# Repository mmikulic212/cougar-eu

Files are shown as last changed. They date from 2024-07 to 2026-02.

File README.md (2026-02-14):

# Throttle Cougar Extended Upgrade

Hardware upgrade for ThrustMaster Cougar TQS throttle quadrant.

## Goal

Enable ThrustMaster Cougar throttle to work independently from Cougar stick, with additional switches and encoders. Uses native USB HID - no additional drivers required.

## MMJoy Firmware

This project uses [MMJoy](https://github.com/MMJoy/mmjoy_en) - open-source USB HID joystick firmware for Arduino.

- **Download**: https://github.com/MMJoy/mmjoy_en/releases
- **Wiki**: https://github.com/MMjoy/mmjoy_en/wiki

## MMJoy Configuration Files

Two pre-configured MMJoy settings are included in `mmjoy_setup/`:

### tm_cougar_mlu_32b+hat.mmjoy
- **32 buttons** + hat switch
- 6 axes (throttle, X, Y, rX, rY, Slider)
- CRS (course) controls mapped as **axes**

### tm_cougar_mlu_36b+hat_crs_asbut.mmjoy
- **36 buttons** + hat switch (32 + **4 additional** buttons)
- 6 axes (throttle, X, Y, rX, rY, Slider)
- CRS (course) controls mapped as **buttons** (for target cursor control in simulators)

Both configurations work identically. Choose 36-button version if you want to control target cursor with buttons instead of axes.

## Hardware

### Required Components

| Component | Description | Example |
|---|---|---|
| ThrustMaster Cougar TQS | Original throttle quadrant | N/A |
| Custom PCB | Interface board | Order package in `order/` |
| Arduino Pro Micro | USB HID controller (ATmega 32u4) | Generic clone, 5V/16MHz, USB-C version is recommended |
| 1x 2x8-pin connector | For throttle button matrix | 2x8-pin connector |

### Optional Components

| Component | Description | Example |
|---|---|---|
| 3x 74HC165 | 8-bit shift register | SN74HC165N DIP-16 |
| 9x Toggle Switch | (ON)-OFF-(ON) DPDT | RS PRO 206-6978 |
| 2x Rotary Encoder | KY-040 with push button | KY-040 module |
| 1x 24-pin DIP socket | For Arduino Pro Micro | |
| 3x 16-pin DIP socket | For 74HC165 | 16-pin DIP socket |
| 3x 10-pin connector | For additional buttons (2x5 IDC header) | 10-pin connector |
| Ribbon cable | 10-pin flat cable | or other cables |

### Recomendation

Orignal throttle and other axis potenciometers can stay and work very wel. But I strongly recommend upgrade to Hall sensors. Unfortunatelly this is still  WIP from my side.

## Wiring and Pinout

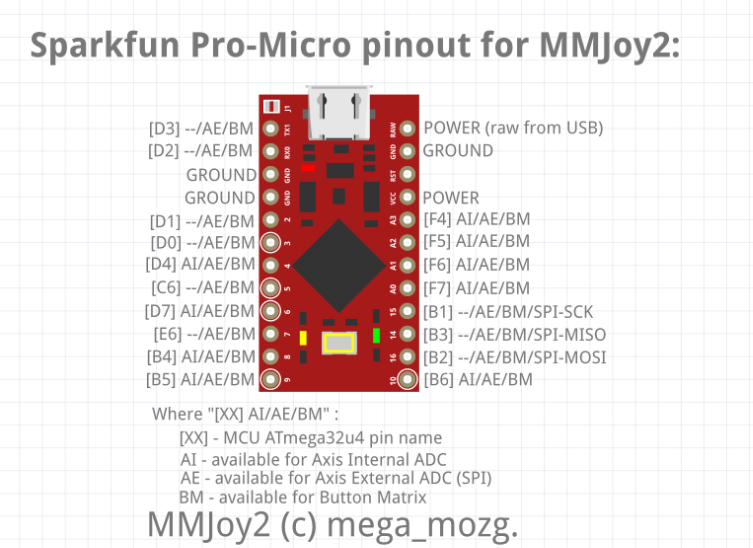
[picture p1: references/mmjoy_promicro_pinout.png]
Pro Micro Pinout


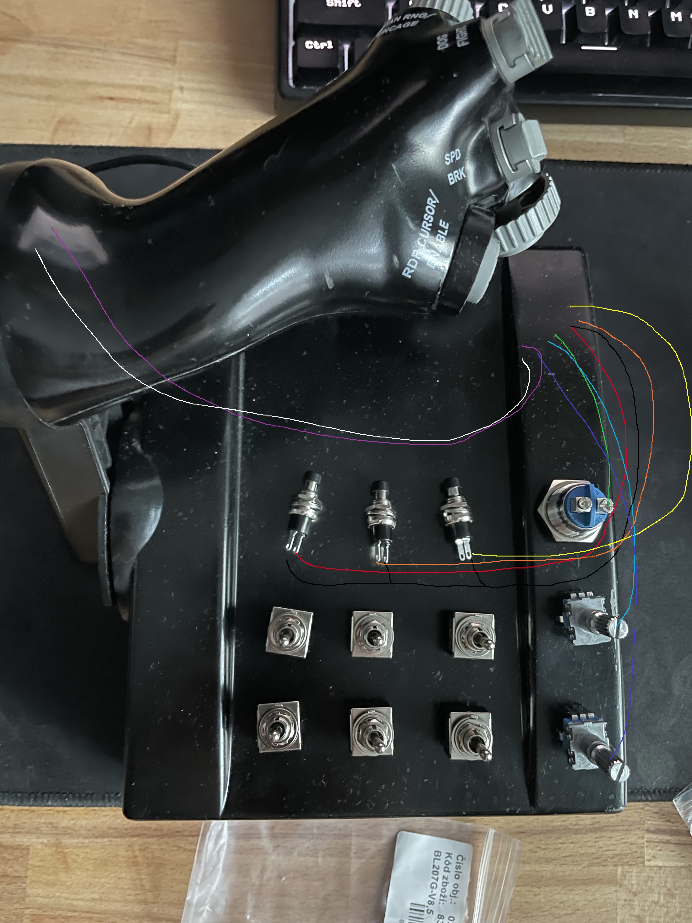
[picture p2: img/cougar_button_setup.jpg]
Button Setup


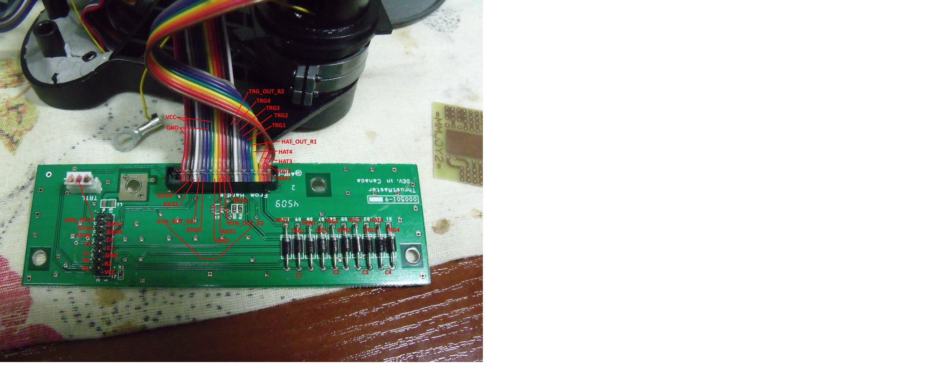
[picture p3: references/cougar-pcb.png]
Cougar PCB Description


### Assembly Images

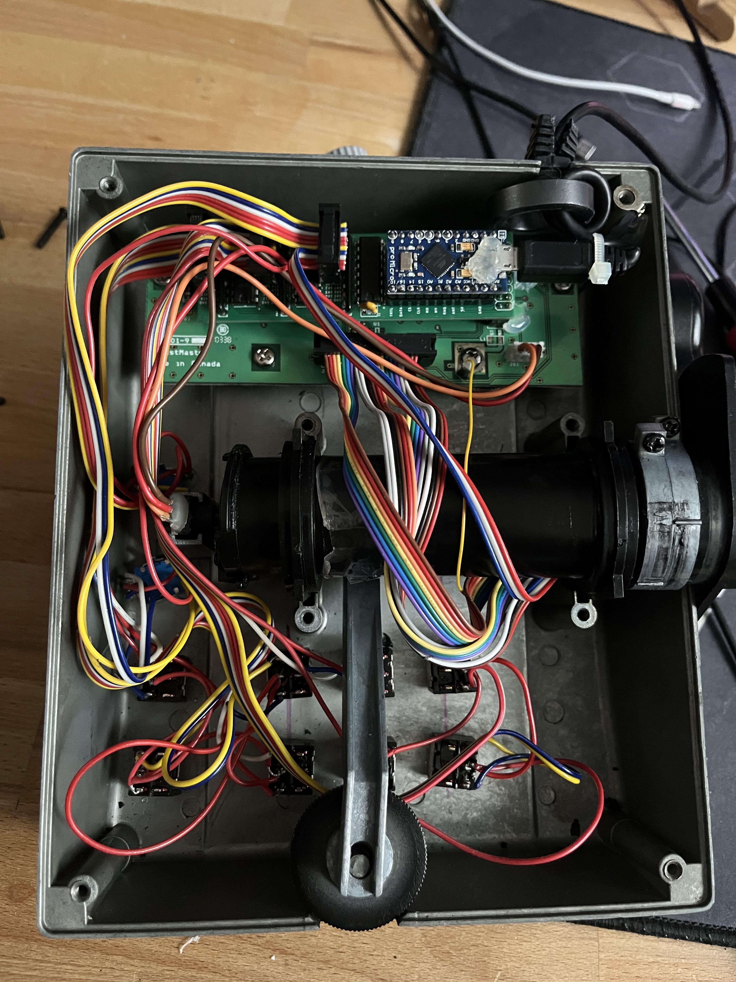
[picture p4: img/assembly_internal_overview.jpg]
Internal Overview

*Internal view showing PCB, Arduino Pro Micro, shift registers, and wiring*

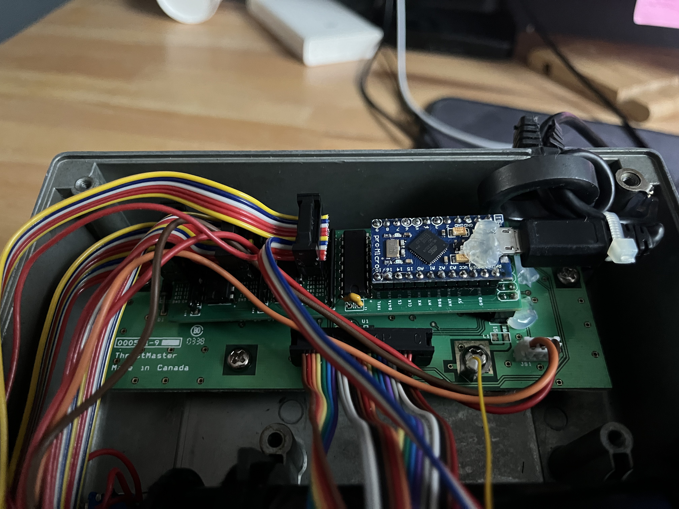
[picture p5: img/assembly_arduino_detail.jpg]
Arduino Detail

*Close-up of Arduino Pro Micro installed in socket with connected wires*

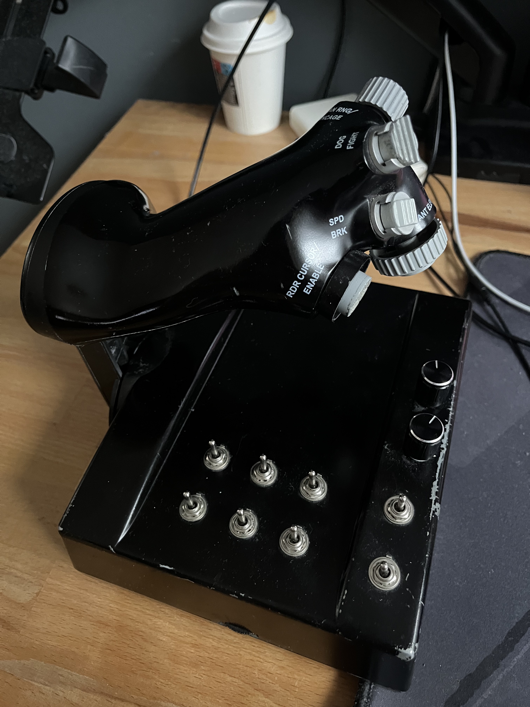
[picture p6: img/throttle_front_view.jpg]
Front View

*Front view of completed throttle with toggle switches*

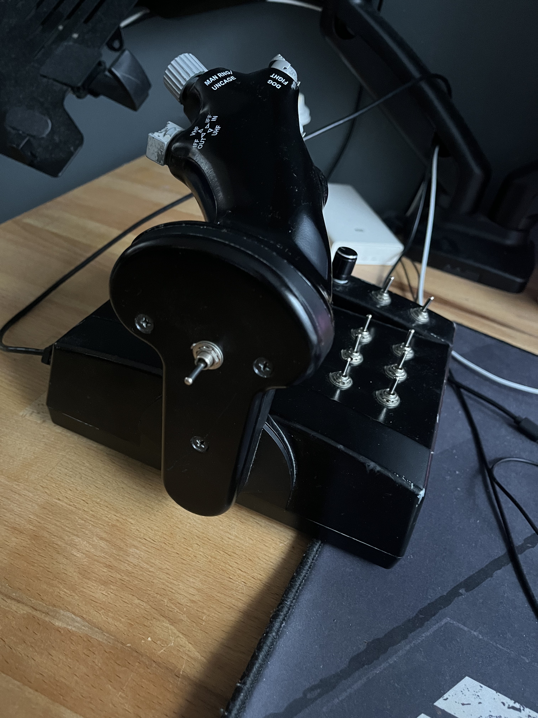
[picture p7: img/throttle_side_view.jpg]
Side View

*Side view showing throttle grip and switch placement*

The custom PCB can be ordered from any PCB manufacturer (JLCPCB, PCBWay, Seeed, etc.) using Gerber files in `order/` folder.

**No electrical modifications to Cougar throttle are required** - simply connect the custom PCB onto Cougar PCB 2x8 DIP connector and connect via USB.

## Getting Started

1. **Order PCB** - Download Gerber files from `order/` folder
2. **Assemble** - Solder components, install Arduino and shift registers in sockets, connect to throttle
3. **Flash firmware** - Upload MMJoy to Arduino Pro Micro ([see MMJoy Wiki](https://github.com/MMjoy/mmjoy_en/wiki/Firmware-upload))
4. **Configure** - Use MMJoy configurator to set up inputs/outputs. Load configuration from `mmjoy_setup/` and modify based on your wiring
5. **Test** - Verify all buttons, encoders, and axes work correctly

## Project Structure

| Folder | Description |
|---|---|
| `board/` | PCB design files (Eagle) |
| `mmjoy_setup/` | MMJoy configuration files |
| `order/` | Gerber files for PCB manufacturing |
| `references/` | Reference documentation |

## License

CC BY-NC-SA 4.0 - Non-commercial use only, share-alike

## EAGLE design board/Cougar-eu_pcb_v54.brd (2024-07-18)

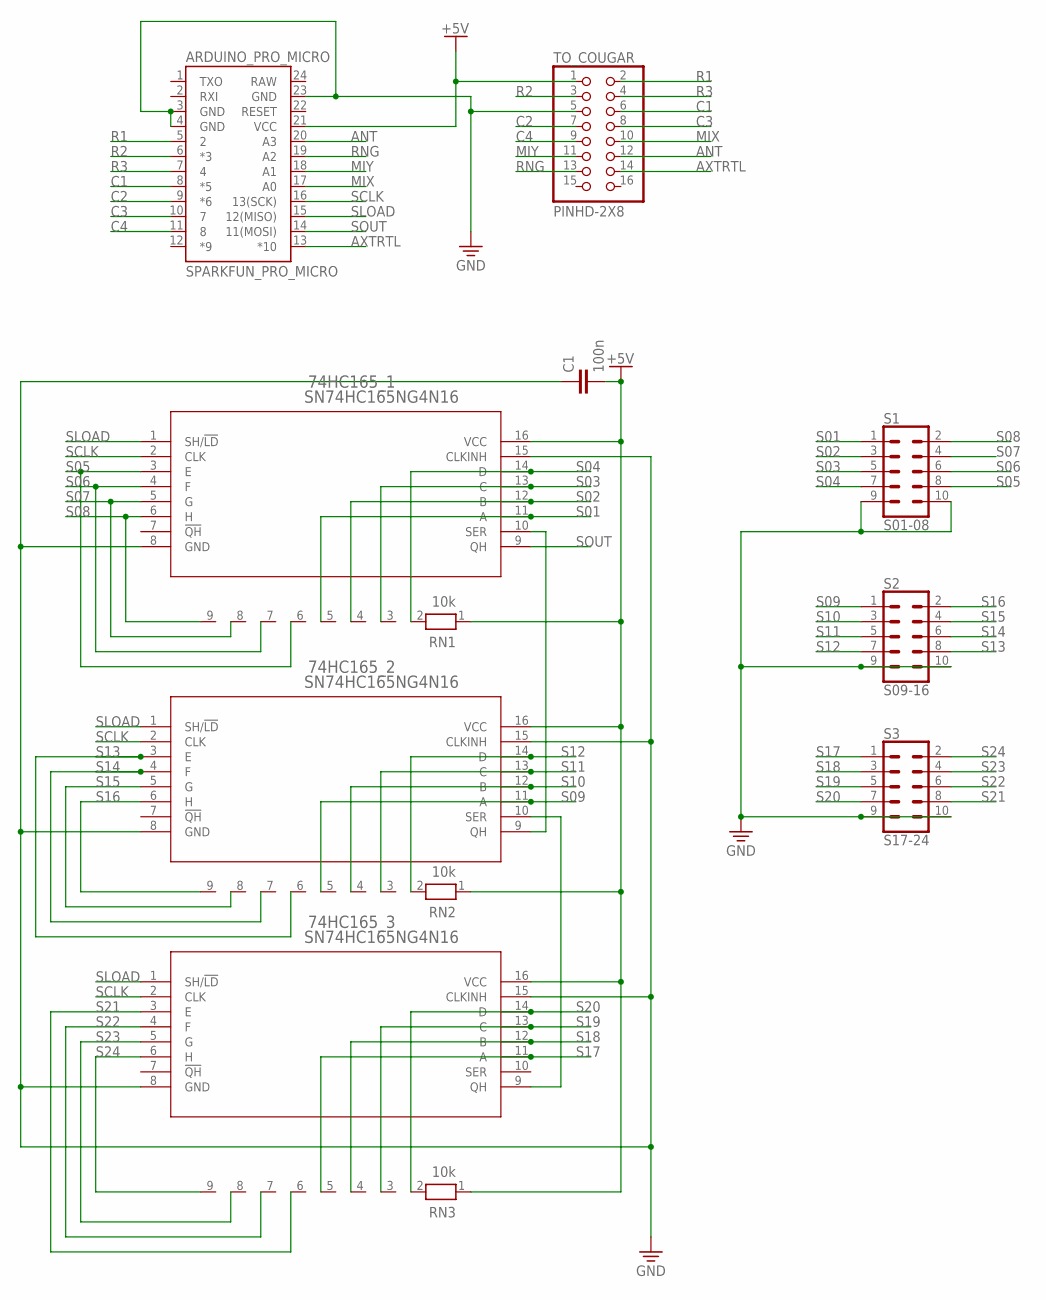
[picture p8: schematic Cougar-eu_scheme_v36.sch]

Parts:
74HC165_1, 74HC165_2, 74HC165_3: SN74HC165NG4N16; N16
ARDUINO_PRO_MICRO: SPARKFUN_PRO_MICRO
C1: 100n; C2.5-3
RN1, RN2, RN3: 10k; RN-9
S1: S01-08; 2X5
S2: S09-16; 2X5
S3: S17-24; 2X5
TO_COUGAR: PINHD-2X8; 2X08

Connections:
+5V: 74HC165_1.16 (VCC), 74HC165_2.16 (VCC), 74HC165_3.16 (VCC), ARDUINO_PRO_MICRO.21 (VCC), C1.2, RN1.1, RN2.1, RN3.1, TO_COUGAR.1
ANT: ARDUINO_PRO_MICRO.20 (A3), TO_COUGAR.12
AXTRTL: ARDUINO_PRO_MICRO.13 (*10), TO_COUGAR.14
C1: ARDUINO_PRO_MICRO.8 (*5), TO_COUGAR.6
C2: ARDUINO_PRO_MICRO.9 (*6), TO_COUGAR.7
C3: ARDUINO_PRO_MICRO.10 (7), TO_COUGAR.8
C4: ARDUINO_PRO_MICRO.11 (8), TO_COUGAR.9
GND: 74HC165_1.8 (GND), 74HC165_1.15 (CLKINH), 74HC165_2.8 (GND), 74HC165_2.15 (CLKINH), 74HC165_3.8 (GND), 74HC165_3.15 (CLKINH), ARDUINO_PRO_MICRO.3 (GND), ARDUINO_PRO_MICRO.4 (GND), ARDUINO_PRO_MICRO.23 (GND), C1.1, S1.9, S1.10, S2.9, S2.10, S3.9, S3.10, TO_COUGAR.5
MIX: ARDUINO_PRO_MICRO.17 (A0), TO_COUGAR.10
MIY: ARDUINO_PRO_MICRO.18 (A1), TO_COUGAR.11
unnamed: 74HC165_1.10 (SER), 74HC165_2.9 (QH)
unnamed: 74HC165_2.10 (SER), 74HC165_3.9 (QH)
R1: ARDUINO_PRO_MICRO.5 (2), TO_COUGAR.2
R2: ARDUINO_PRO_MICRO.6 (*3), TO_COUGAR.3
R3: ARDUINO_PRO_MICRO.7 (4), TO_COUGAR.4
RAW: ARDUINO_PRO_MICRO.24 (RAW)
RNG: ARDUINO_PRO_MICRO.19 (A2), TO_COUGAR.13
S01: 74HC165_1.11 (A), RN1.5, S1.1
S02: 74HC165_1.12 (B), RN1.4, S1.3
S03: 74HC165_1.13 (C), RN1.3, S1.5
S04: 74HC165_1.14 (D), RN1.2, S1.7
S05: 74HC165_1.3 (E), RN1.6, S1.8
S06: 74HC165_1.4 (F), RN1.7, S1.6
S07: 74HC165_1.5 (G), RN1.8, S1.4
S08: 74HC165_1.6 (H), RN1.9, S1.2
S09: 74HC165_2.11 (A), RN2.5, S2.1
S10: 74HC165_2.12 (B), RN2.4, S2.3
S11: 74HC165_2.13 (C), RN2.3, S2.5
S12: 74HC165_2.14 (D), RN2.2, S2.7
S13: 74HC165_2.3 (E), RN2.6, S2.8
S14: 74HC165_2.4 (F), RN2.7, S2.6
S15: 74HC165_2.5 (G), RN2.8, S2.4
S16: 74HC165_2.6 (H), RN2.9, S2.2
S17: 74HC165_3.11 (A), RN3.5, S3.1
S18: 74HC165_3.12 (B), RN3.4, S3.3
S19: 74HC165_3.13 (C), RN3.3, S3.5
S20: 74HC165_3.14 (D), RN3.2, S3.7
S21: 74HC165_3.3 (E), RN3.6, S3.8
S22: 74HC165_3.4 (F), RN3.7, S3.6
S23: 74HC165_3.5 (G), RN3.8, S3.4
S24: 74HC165_3.6 (H), RN3.9, S3.2
SCLK: 74HC165_1.2 (CLK), 74HC165_2.2 (CLK), 74HC165_3.2 (CLK), ARDUINO_PRO_MICRO.16 (13(SCK))
SLOAD: 74HC165_1.1 (SH/!LD), 74HC165_2.1 (SH/!LD), 74HC165_3.1 (SH/!LD), ARDUINO_PRO_MICRO.15 (12(MISO))
SOUT: 74HC165_1.9 (QH), ARDUINO_PRO_MICRO.14 (11(MOSI))

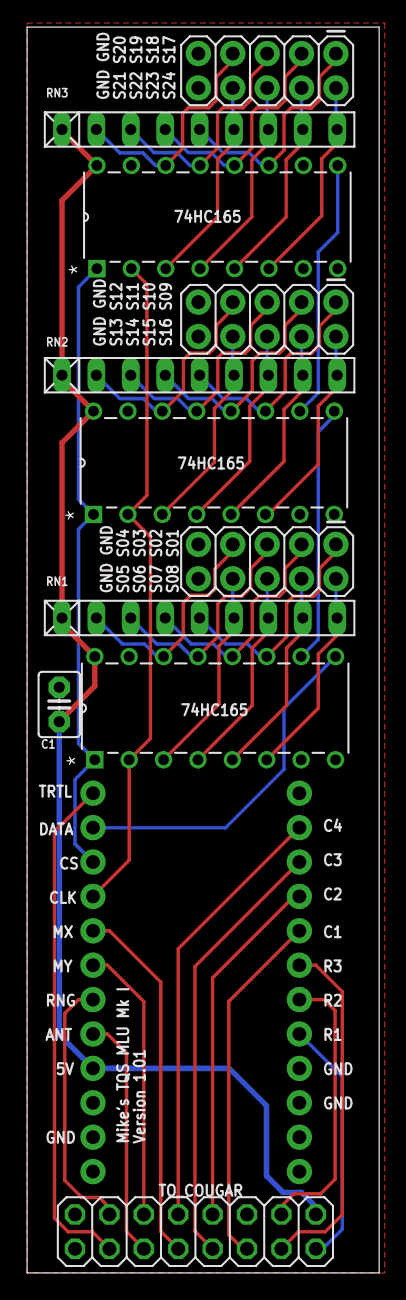
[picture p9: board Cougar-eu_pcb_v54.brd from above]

Board: 2 copper layers, 26.0 x 92.0 mm, 12 parts (0 on the bottom side), 43 nets.

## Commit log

2024-07-18 add board
    [Cougar-eu_pcb_v54.brd, Cougar-eu_scheme_v36.sch]
2026-02-14 Add comprehensive README with MMJoy firmware guide, hardware components table, and assembly images
    - Rewrote README with detailed project description
    - Added MMJoy firmware section with download/wiki links
    - Added hardware components tables (required + optional)
    - Added PCB ordering info (any manufacturer)
    - Added Getting Started guide (Order → Assemble → Flash → Configure → Test)
    - Added assembly images with descriptions
    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

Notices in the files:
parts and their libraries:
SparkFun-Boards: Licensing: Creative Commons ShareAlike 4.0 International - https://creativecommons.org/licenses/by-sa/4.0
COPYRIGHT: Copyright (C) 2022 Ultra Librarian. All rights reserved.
